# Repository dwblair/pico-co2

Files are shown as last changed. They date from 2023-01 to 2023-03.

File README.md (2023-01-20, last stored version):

3xAA holder [keystone 2464 on digikey](https://www.digikey.com/en/products/detail/keystone-electronics/2464/303813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)

[keystone 2464 datasheet](https://www.keyelco.com/userAssets/file/M65p28.pdf)

3xAAA [keystone 2479](https://www.digikey.com/en/products/detail/keystone-electronics/2479/303824)

[AA and AAA Keystone battery holders datasheet](https://www.keyelco.com/userAssets/file/M65p28.pdf)

m2.5 wingnut [https://www.walmart.com/ip/M2-5-Stainless-Steel-Coarse-Female-Thread-Instal-Tool-Fastener-Wing-Nut-100pcs/139536392](https://www.walmart.com/ip/M2-5-Stainless-Steel-Coarse-Female-Thread-Instal-Tool-Fastener-Wing-Nut-100pcs/139536392)

m3 slotted thumb screw [https://www.digikey.com/en/products/detail/essentra-components/50M030050T005/11640409](https://www.digikey.com/en/products/detail/essentra-components/50M030050T005/11640409)

adalogger schematic [https://learn.adafruit.com/adafruit-adalogger-featherwing/downloads](https://learn.adafruit.com/adafruit-adalogger-featherwing/downloads)

PCF8523T RTC -- [https://www.digikey.com/en/products/detail/nxp-usa-inc/PCF8523T-1-118/2530422](https://www.digikey.com/en/products/detail/nxp-usa-inc/PCF8523T-1-118/2530422)

adafruit adalogger schematic [https://cdn-learn.adafruit.com/assets/assets/000/044/116/original/feather_schem.png?1500667618](https://cdn-learn.adafruit.com/assets/assets/000/044/116/original/feather_schem.png?1500667618)

32 khz crystal on digikey [https://www.digikey.com/en/products/detail/transko-electronics,-inc./CS31-32.768K-9-TR/13427726?utm_adgroup=Crystals&utm_source=google&utm_medium=cpc&utm_campaign=Shopping_DK%2BSupplier_Transko%20Electronics%20Inc&utm_term=&utm_content=Crystals&gclid=CjwKCAiA8OmdBhAgEiwAShr40zgUk4ZO5pCGyjE0bjxWT38Y2moxhUrvTism52RVnNrdhaW5F5u-MxoCXEMQAvD_BwE](https://www.digikey.com/en/products/detail/transko-electronics,-inc./CS31-32.768K-9-TR/13427726?utm_adgroup=Crystals&utm_source=google&utm_medium=cpc&utm_campaign=Shopping_DK%2BSupplier_Transko%20Electronics%20Inc&utm_term=&utm_content=Crystals&gclid=CjwKCAiA8OmdBhAgEiwAShr40zgUk4ZO5pCGyjE0bjxWT38Y2moxhUrvTism52RVnNrdhaW5F5u-MxoCXEMQAvD_BwE)

pcf8523T rtc [https://www.digikey.com/en/products/detail/nxp-usa-inc./PCF8523T%2F1,118/2530784?utm_adgroup=Integrated%20Circuits%20%28ICs%29&utm_source=google&utm_medium=cpc&utm_campaign=Shopping_Supplier_NXP%20USA%20Inc_0568_Co-op&utm_term=&utm_content=Integrated%20Circuits%20%28ICs%29&gclid=CjwKCAiA8OmdBhAgEiwAShr408KoTeQXFooxG_pMahZUPYFPXL6n5eyTnglh__SAioUxeqxWUZ0JkhoCWvAQAvD_BwE](https://www.digikey.com/en/products/detail/nxp-usa-inc./PCF8523T%2F1,118/2530784?utm_adgroup=Integrated%20Circuits%20%28ICs%29&utm_source=google&utm_medium=cpc&utm_campaign=Shopping_Supplier_NXP%20USA%20Inc_0568_Co-op&utm_term=&utm_content=Integrated%20Circuits%20%28ICs%29&gclid=CjwKCAiA8OmdBhAgEiwAShr408KoTeQXFooxG_pMahZUPYFPXL6n5eyTnglh__SAioUxeqxWUZ0JkhoCWvAQAvD_BwE)

crystal -- abracon abs25 -- [https://www.digikey.com/en/products/detail/abracon-llc/ABS25-32-768KHZ-T/675361](https://www.digikey.com/en/products/detail/abracon-llc/ABS25-32-768KHZ-T/675361)

keystone 1056 battery holder for cr1220 [https://www.digikey.com/en/products/detail/keystone-electronics/1056/2020198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](https://www.digikey.com/en/products/detail/keystone-electronics/1056/2020198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)

keystone 1056 datasheet [https://www.keyelco.com/userAssets/file/M65p2.pdf](https://www.keyelco.com/userAssets/file/M65p2.pdf)

feather m0 lora schematic [https://cdn-learn.adafruit.com/assets/assets/000/032/914/original/feather_schem.png?1465421956](https://cdn-learn.adafruit.com/assets/assets/000/032/914/original/feather_schem.png?1465421956)

mcp73831 batt charger [https://www.digikey.com/en/products/detail/microchip-technology/MCP73831T-4ADI%2FOT/9642871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](https://www.digikey.com/en/products/detail/microchip-technology/MCP73831T-4ADI%2FOT/9642871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)

mbr120 diodes [https://www.digikey.com/en/products/detail/onsemi/MBR120LSFT3G/1477155](https://www.digikey.com/en/products/detail/onsemi/MBR120LSFT3G/1477155)

digikey version of ssd1306 display: [https://www.digikey.com/en/products/detail/universal-solder-electronics-ltd/OLED%2520128X64%25201.3%2522%2520I2C/16822118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](https://www.digikey.com/en/products/detail/universal-solder-electronics-ltd/OLED%2520128X64%25201.3%2522%2520I2C/16822118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)

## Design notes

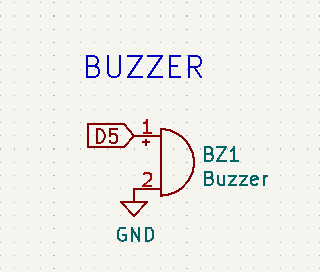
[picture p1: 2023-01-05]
REV_X/hardware/references/buzzer.png

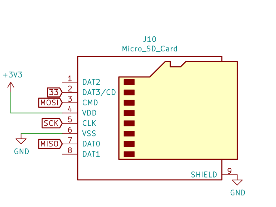
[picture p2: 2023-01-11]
REV_X/hardware/references/microsd_pinout.png

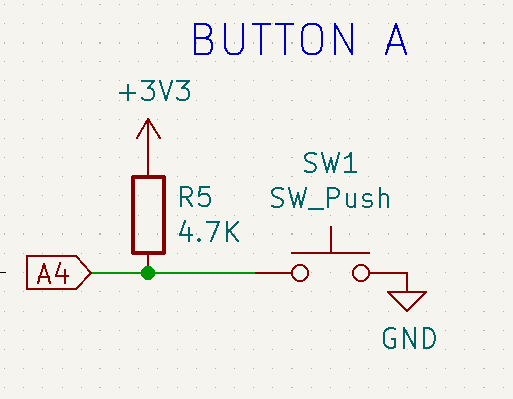
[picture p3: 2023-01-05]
REV_X/hardware/references/button.png

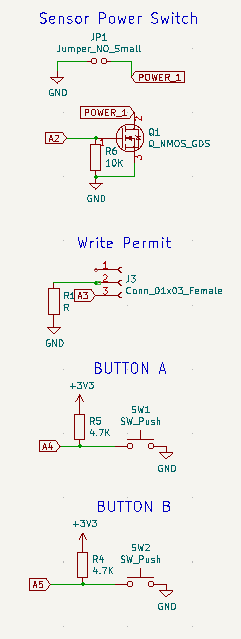
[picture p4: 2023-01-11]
REV_X/hardware/references/buttons_write_permit.png

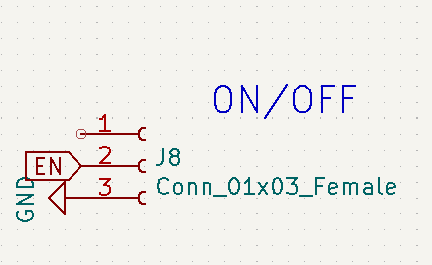
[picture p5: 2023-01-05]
REV_X/hardware/references/power_enable.png

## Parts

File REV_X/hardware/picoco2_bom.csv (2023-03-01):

Id | Designator | Package | Quantity | Designation | Supplier and ref
1 | J2 | DM3D-SF_outline | 1 | Micro_SD_Card
2 | U4 | SOIC-8_3.9x4.9mm_P1.27mm | 1 | PCF8523T
3 | C2,C1,C3 | C_0603_1608Metric_Pad1.08x0.95mm_HandSolder | 3 | 10uF
4 | R13,R12 | R_Axial_DIN0204_L3.6mm_D1.6mm_P7.62mm_Horizontal | 2 | 4.7K
5 | J3,J1 | PinSocket_1x03_P2.54mm_Vertical | 2 | Conn_01x03_Female
6 | H3,H1,H2,H4 | MountingHole_3.2mm_M3 | 4 | MountingHole
7 | BT2 | BatteryHolder_Keystone_2468_2xAAA | 1 | Battery
8 | SW2,SW1 | SW_Tactile_SPST_Angled_PTS645Vx31-2LFS | 2 | SW_Push
9 | R3,R8,R9 | R_0603_1608Metric_Pad0.98x0.95mm_HandSolder | 3 | 10K
10 | U3 | ssd1306_a | 1 | ssd1306
11 | R11,R10 | R_Axial_DIN0204_L3.6mm_D1.6mm_P7.62mm_Horizontal | 2 | 10K
12 | Q1 | SOT-23 | 1 | Q_NMOS_GDS
13 | R6,R7 | R_0603_1608Metric_Pad0.98x0.95mm_HandSolder | 2 | 1K
14 | U5 | SOT-23-5 | 1 | MCP73831-2-OT
15 | D1,D5 | D_SOD-123F | 2 | D
16 | BT3 | JST_PH_S2B-PH-SM4-TB_1x02-1MP_P2.00mm_Horizontal | 1 | Battery
17 | BT1 | CR1220-2 | 1 | CR1220
18 | U1 | RPi_PicoW_SMD | 1 | PicoW
19 | R4 | R_0603_1608Metric_Pad0.98x0.95mm_HandSolder | 1 | R
20 | R1,R2 | R_0603_1608Metric_Pad0.98x0.95mm_HandSolder | 2 | 4.7K
21 | JP1 | SolderJumper-2_P1.3mm_Open_Pad1.0x1.5mm | 1 | SolderJumper_2_Open
22 | D4 | LED_0603_1608Metric_Pad1.05x0.95mm_HandSolder | 1 | LED
23 | BZ1 | MagneticBuzzer_Kobitone_254-EMB84Q-RO | 1 | Buzzer
24 | Y1 | Crystal_SMD_Abracon_ABS25-4Pin_8.0x3.8mm | 1 | 32KHz
25 | U2 | scd30_a | 1 | scd30
26 | D2 | D_5W_P10.16mm_Horizontal | 1 | D

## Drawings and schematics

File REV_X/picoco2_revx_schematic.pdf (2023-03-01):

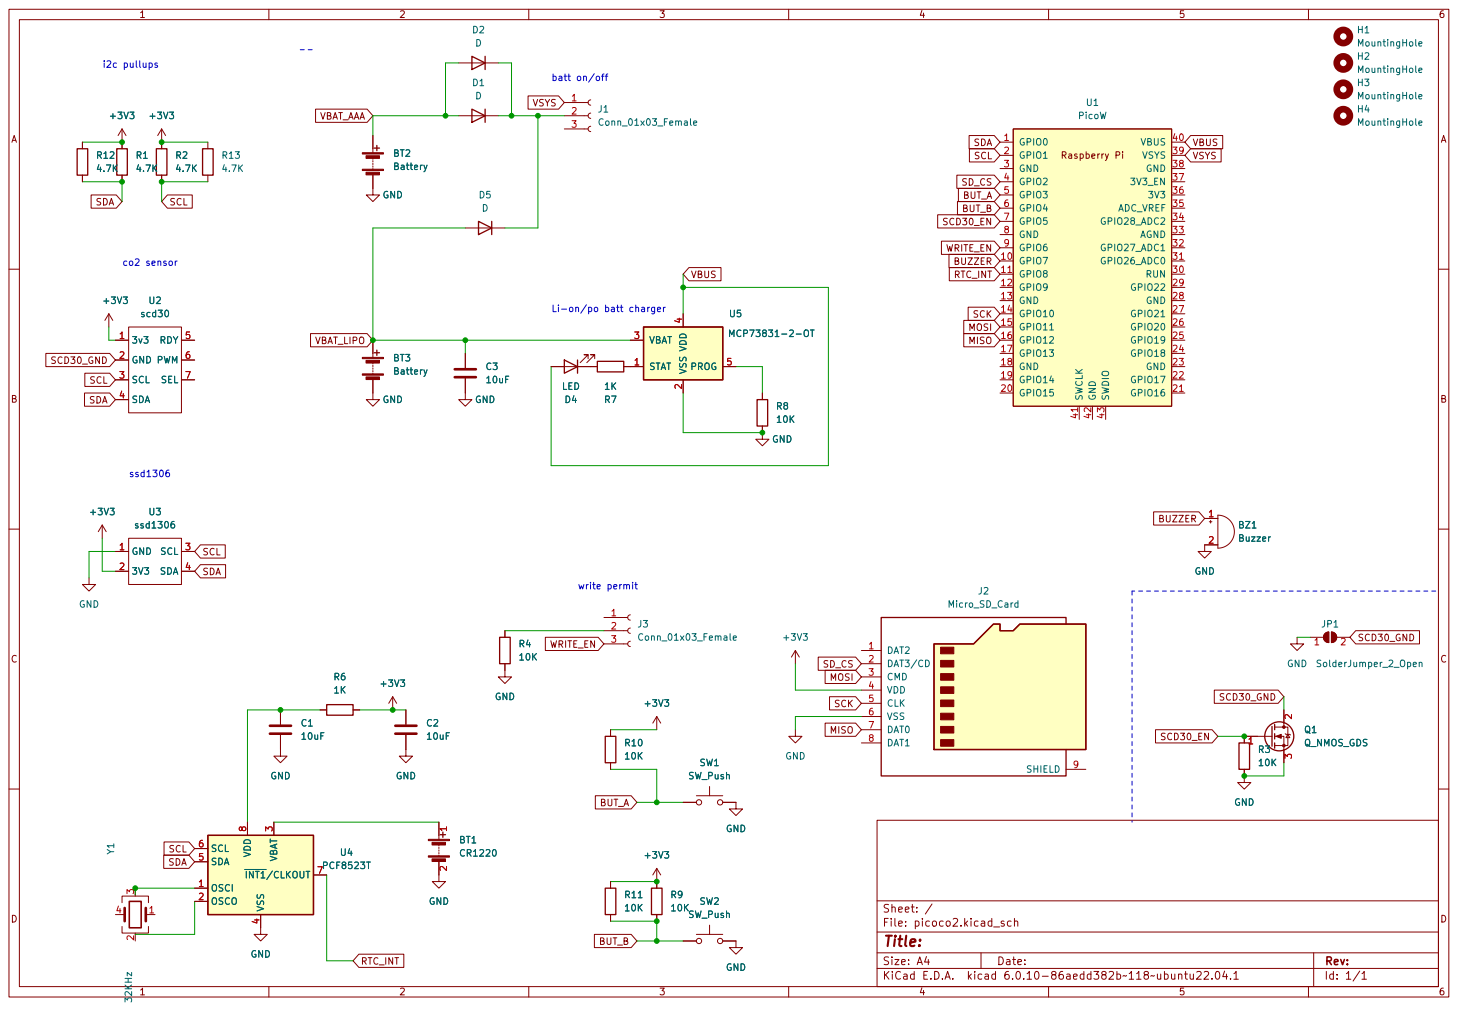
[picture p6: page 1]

i2c pullups
Li-on/po batt charger batt on/off co2 sensor

8 U4 PCF8523T DAT2 1 DAT3/CD 2 CMD 3 VDD 4 CLK 5 VSS 6 DAT0 7 DAT1 8 SHIELD 9

1 2 BT1 CR1220 GND OSCI 1 OSCO 2 VBAT

4 SDA 5 SCL 6 ~{INT1}/CLKOUT 7 VDD
SDA

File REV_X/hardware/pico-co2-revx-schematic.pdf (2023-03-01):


i2c pullups
Li-on/po batt charger batt on/off co2 sensor

4 SDA 5 SCL 6 ~{INT1}/CLKOUT 7 VDD

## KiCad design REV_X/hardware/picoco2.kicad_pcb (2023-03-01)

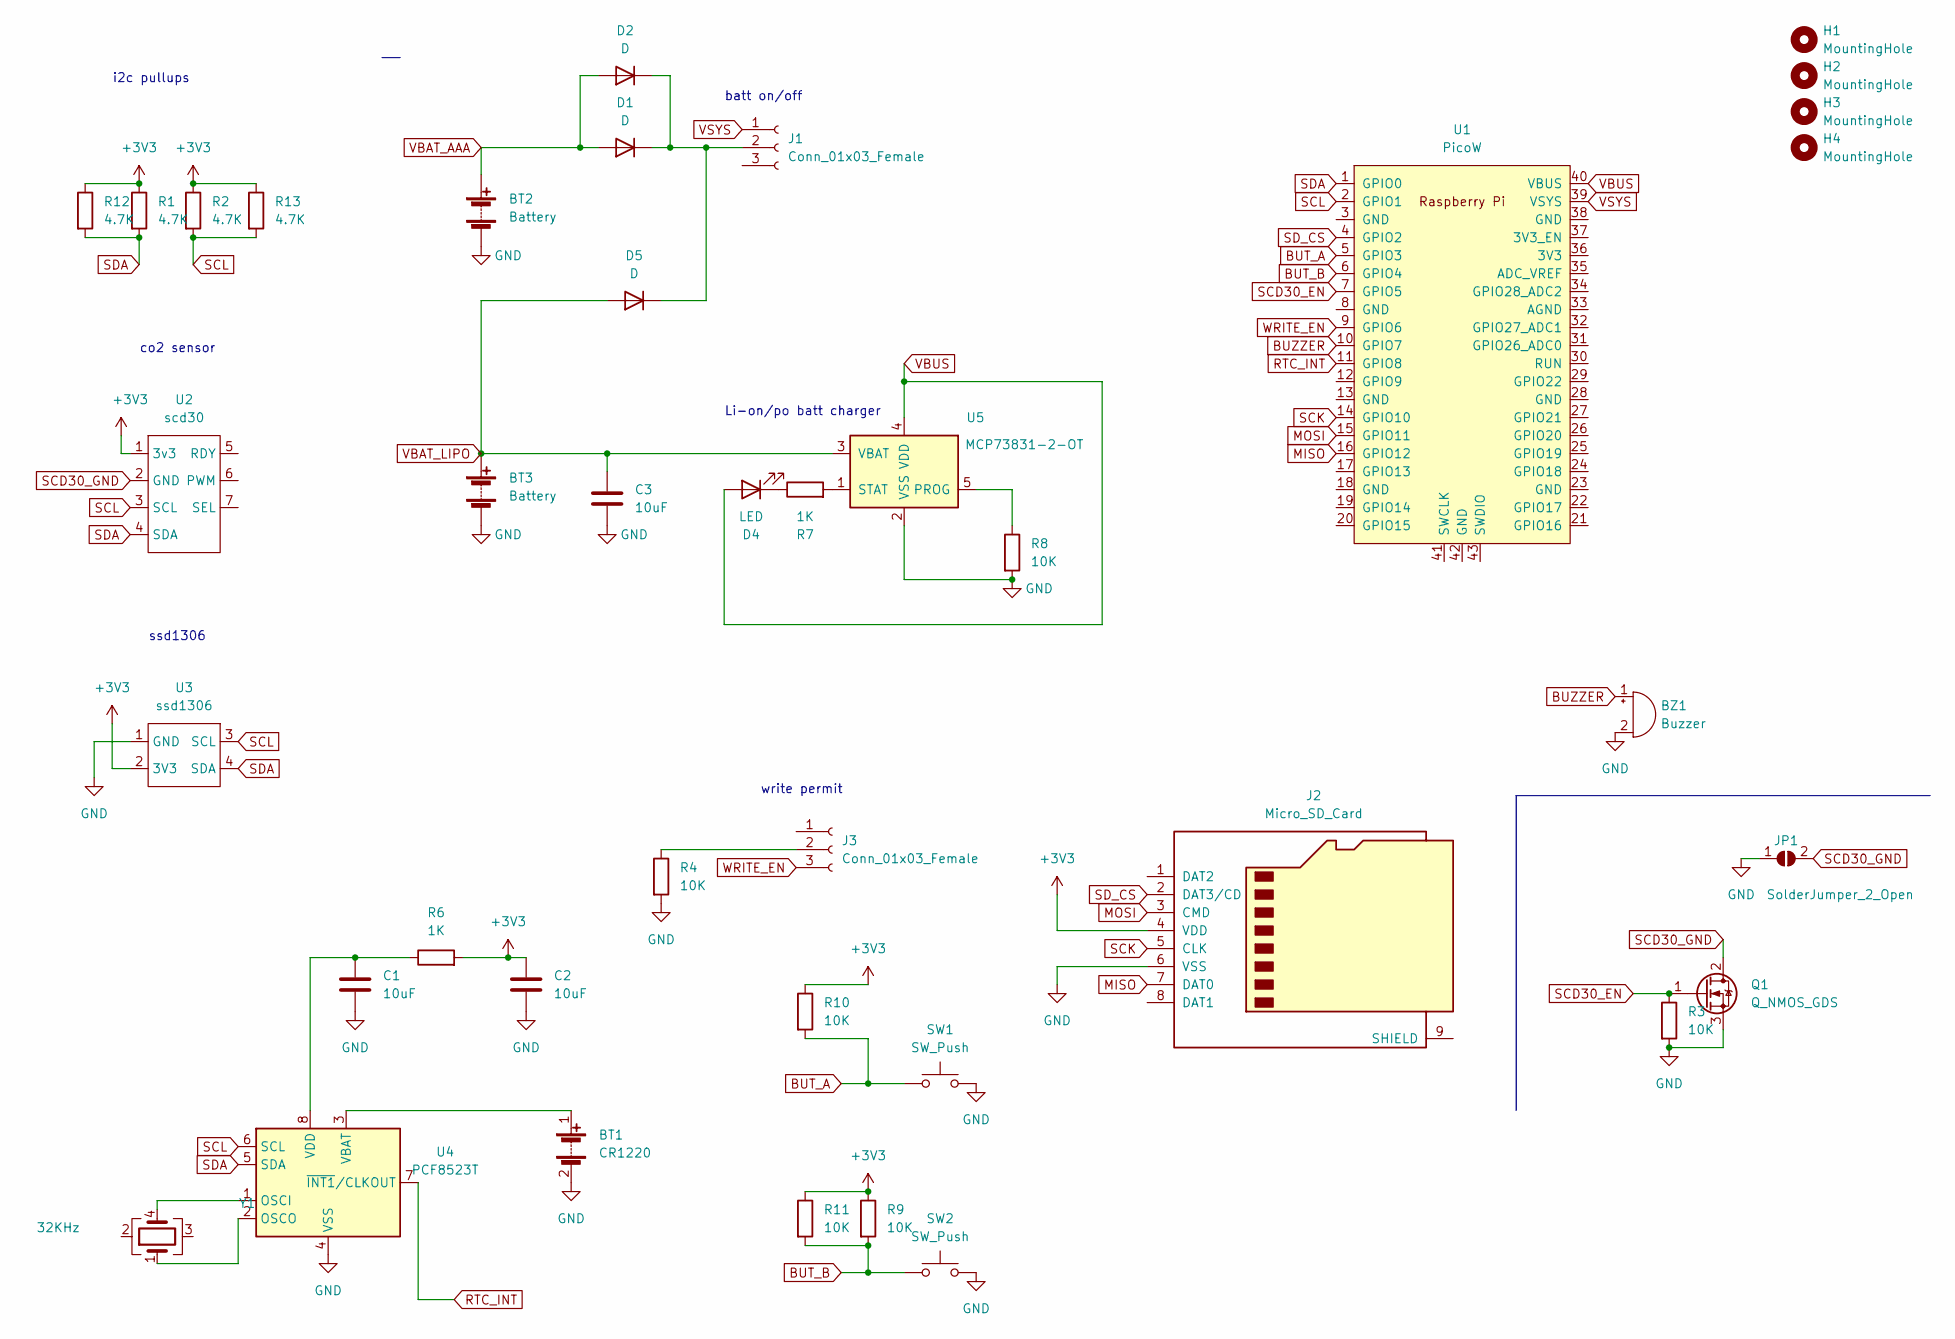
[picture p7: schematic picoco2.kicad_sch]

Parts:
BT1: CR1220; CR1220-2
BT2: Battery; BatteryHolder_Keystone_2468_2xAAA
BT3: Battery; JST_PH_S2B-PH-SM4-TB_1x02-1MP_P2.00mm_Horizontal
BZ1: Buzzer; MagneticBuzzer_Kobitone_254-EMB84Q-RO
C1, C2, C3: 10uF; C_0603_1608Metric_Pad1.08x0.95mm_HandSolder
D1, D5: D; D_SOD-123F
D2: D; D_5W_P10.16mm_Horizontal
D4: LED; LED_0603_1608Metric_Pad1.05x0.95mm_HandSolder
H1, H2, H3, H4: MountingHole; MountingHole_3.2mm_M3
J1, J3: Conn_01x03_Female; PinSocket_1x03_P2.54mm_Vertical
J2: Micro_SD_Card; DM3D-SF_outline
JP1: SolderJumper_2_Open; SolderJumper-2_P1.3mm_Open_Pad1.0x1.5mm
Q1: Q_NMOS_GDS; SOT-23
R1, R2: 4.7K; R_0603_1608Metric_Pad0.98x0.95mm_HandSolder
R3, R4, R8, R9: 10K; R_0603_1608Metric_Pad0.98x0.95mm_HandSolder
R6, R7: 1K; R_0603_1608Metric_Pad0.98x0.95mm_HandSolder
R10, R11: 10K; R_Axial_DIN0204_L3.6mm_D1.6mm_P7.62mm_Horizontal
R12, R13: 4.7K; R_Axial_DIN0204_L3.6mm_D1.6mm_P7.62mm_Horizontal
SW1, SW2: SW_Push; SW_Tactile_SPST_Angled_PTS645Vx31-2LFS
U1: PicoW; RPi_PicoW_SMD
U2: scd30; scd30_a
U3: ssd1306; ssd1306_a
U4: PCF8523T; SOIC-8_3.9x4.9mm_P1.27mm
U5: MCP73831-2-OT; SOT-23-5
Y1: 32KHz; Crystal_SMD_Abracon_ABS25-4Pin_8.0x3.8mm

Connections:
+3V3: C2.1, J2.4 (VDD), R1.1, R2.1, R6.2, R9.1, R10.1, R11.1, R12.1, R13.1, U2.1 (3v3), U3.2 (3V3)
BUT_A: R10.2, SW1.1, U1.5 (GPIO3)
BUT_B: R9.2, R11.2, SW2.1, U1.6 (GPIO4)
BUZZER: BZ1.1 (-), U1.10 (GPIO7)
GND: BT1.2 (-), BT2.2 (-), BT3.2 (-), BZ1.2 (+), C1.2, C2.2, C3.2, J2.6 (VSS), JP1.1 (A), Q1.3 (S), R3.2, R4.2, R8.2, SW1.2, SW2.2, U3.1 (GND), U4.4 (VSS), U5.2 (VSS)
MISO: J2.7 (DAT0), U1.16 (GPIO12)
MOSI: J2.3 (CMD), U1.15 (GPIO11)
unnamed: BT1.1 (+), U4.3 (VBAT)
unnamed: C1.1, R6.1, U4.8 (VDD)
unnamed: D1.1 (K), D2.1 (K), D5.1 (K), J1.2
unnamed: D4.1 (K), R7.1
unnamed: J3.2, R4.1
unnamed: R7.2, U5.1 (STAT)
unnamed: R8.1, U5.5 (PROG)
unnamed: U4.1 (OSCI), Y1.4
unnamed: U4.2 (OSCO), Y1.1
RTC_INT: U1.11 (GPIO8), U4.7 (~INT1/CLKOUT)
SCD30_EN: Q1.1 (G), R3.1, U1.7 (GPIO5)
SCD30_GND: JP1.2 (B), Q1.2 (D), U2.2 (GND)
SCK: J2.5 (CLK), U1.14 (GPIO10)
SCL: R2.2, R13.2, U1.2 (GPIO1), U2.3 (SCL), U3.3 (SCL), U4.6 (SCL)
SDA: R1.2, R12.2, U1.1 (GPIO0), U2.4 (SDA), U3.4 (SDA), U4.5 (SDA)
SD_CS: J2.2 (DAT3/CD), U1.4 (GPIO2)
VBAT_AAA: BT2.1 (+), D1.2 (A), D2.2 (A)
VBAT_LIPO: BT3.1 (+), C3.1, D5.2 (A), U5.3 (VBAT)
VBUS: D4.2 (A), U1.40 (VBUS), U5.4 (VDD)
VSYS: J1.1, U1.39 (VSYS)
WRITE_EN: J3.3, U1.9 (GPIO6)

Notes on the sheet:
i2c pullups
write permit
batt on/off
Li-on/po batt charger
co2 sensor
ssd1306

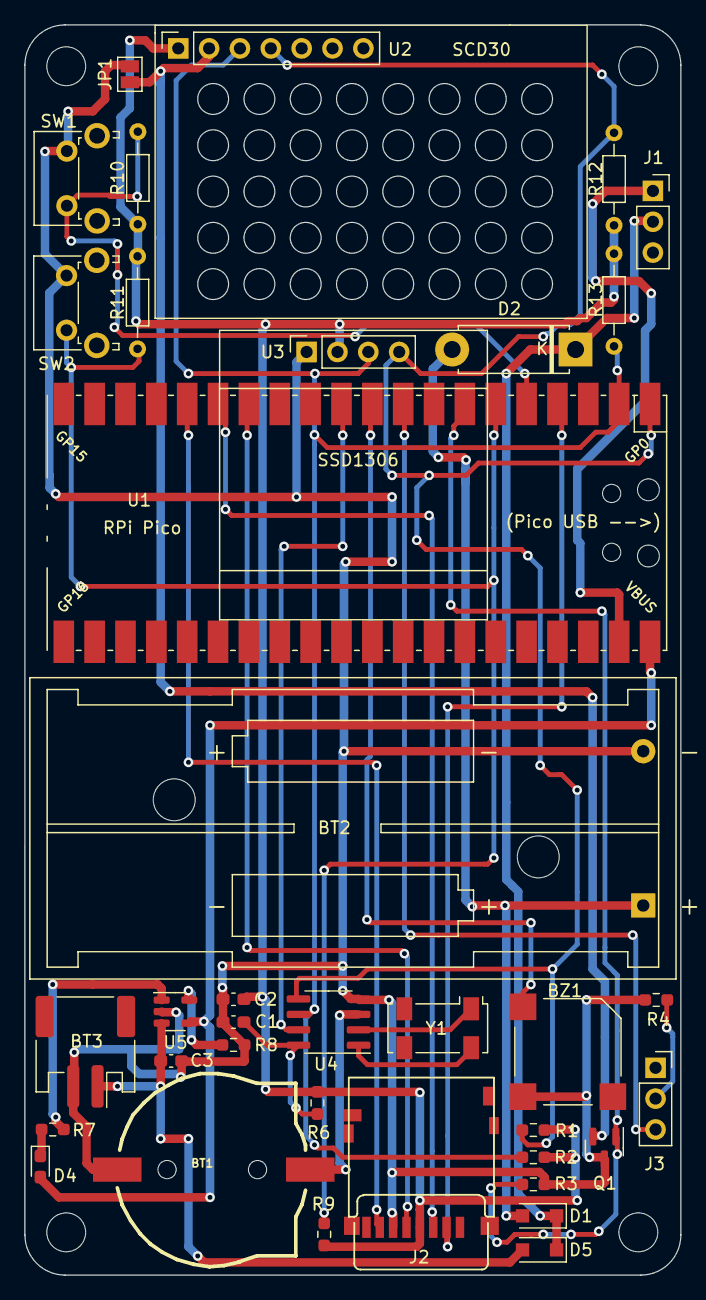
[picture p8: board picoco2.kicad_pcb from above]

Board: 2 copper layers, 54.0 x 102.9 mm, 40 parts (0 on the bottom side), 28 nets.

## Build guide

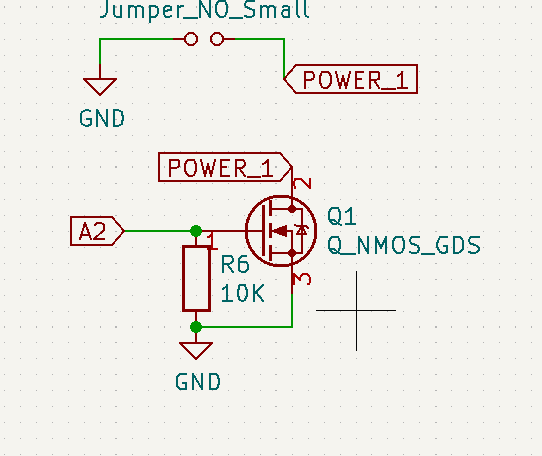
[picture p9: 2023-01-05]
REV_X/hardware/references/mosfet_setup.png

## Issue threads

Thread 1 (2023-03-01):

Fixes for REV_X (might need to break this up into several issues)

dwblair, 2023-03-01:
- R10 needs a matching SMT resistor
- Need to check mosfet circuit (especially, resistors)
- Use 3V3_EN on power switch
- Route 3V3 and GND!
- Add breakout pins?
- Better marking for EN | ~EN
- Reduce width of board to footprint of AAA holder
- Swap in buzzer that is avail on digikey
- Move microSD up into board a few mm
- Better mounting solution for SSD1306 display?

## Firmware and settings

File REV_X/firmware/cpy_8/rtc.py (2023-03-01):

import busio
import adafruit_pcf8523
import time
import board

myI2C = busio.I2C(scl=board.GP1, sda=board.GP0)

rtc = adafruit_pcf8523.PCF8523(myI2C)

days = ("Sunday", "Monday", "Tuesday", "Wednesday", "Thursday", "Friday", "Saturday")

if False:   # change to True if you want to write the time!
    #                     year, mon, date, hour, min, sec, wday, yday, isdst
    t = time.struct_time((2023,  2,   26,   14,  51,  15,    0,   -1,    -1))
    # you must set year, mon, date, hour, min, sec and weekday
    # yearday is not supported, isdst can be set but we don't do anything with it at this time
    
    print("Setting time to:", t)     # uncomment for debugging
    rtc.datetime = t
    print()
    
while True:
    t = rtc.datetime
    #print(t)     # uncomment for debugging

    print("The date is %s %d/%d/%d" % (days[t.tm_wday], t.tm_mday, t.tm_mon, t.tm_year))
    print("The time is %d:%02d:%02d" % (t.tm_hour, t.tm_min, t.tm_sec))
    
    time.sleep(1) # wait a second

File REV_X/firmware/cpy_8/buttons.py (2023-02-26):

import board
import digitalio
from adafruit_debouncer import Debouncer

pin = digitalio.DigitalInOut(board.GP4)
pin.direction = digitalio.Direction.INPUT
pin.pull = digitalio.Pull.UP
switch = Debouncer(pin)

while True:
    switch.update()
    if switch.fell:
        print('Just pressed')
    if switch.rose:
        print('Just released')
    if switch.value:
        print('not pressed')
    else:
        print('pressed')

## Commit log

2023-01-11 basic layout done
    [picoco2.kicad_pcb, picoco2.kicad_sch]
2023-01-11 rounded edges
    [picoco2.kicad_pcb]
2023-01-12 added i2c resistors
    [picoco2.kicad_pcb, picoco2.kicad_sch]
2023-01-15 finished positioning of holes and parts
    [picoco2.kicad_pcb]
2023-01-15 routed power lines
    [picoco2.kicad_pcb, picoco2.kicad_sch]
2023-01-16 finally finished routing power
    [picoco2.kicad_pcb]
2023-01-16 full routing
    [picoco2.kicad_pcb, picoco2.kicad_sch]
2023-01-16 full routing 2
    [picoco2.kicad_pcb]
2023-01-16 fully routed
    [picoco2.kicad_pcb]
2023-01-20 fully routed, revised ssd1306 display module
    [picoco2.kicad_pcb]
2023-01-20 added label for ssd1306
    [picoco2.kicad_pcb]
2023-01-20 avoided copper keepouts
    [picoco2_cover.kicad_pcb]
2023-01-20 recentered the display
    [picoco2.kicad_pcb, picoco2_cover.kicad_pcb]
2023-01-20 cover, revised base, back
    [picoco2.kicad_pcb, picoco2_back.kicad_pcb]
2023-01-20 minor cosmetics
    [picoco2.kicad_pcb]
2023-02-11 updated values on components
    [picoco2-B_Cu.gbr, picoco2-B_Mask.gbr, picoco2-B_Paste.gbr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]
